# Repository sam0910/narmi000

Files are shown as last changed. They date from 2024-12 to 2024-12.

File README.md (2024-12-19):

## :rocket: 개발환경 구축

-   Clone this repository again, please refer pymakr.conf file.

-   Install Pymakr vscode extension - version 1.1.18

-   Modify pymakr.conf

```
"address": "COM6",
```

-   Click `X Pymakr Console`, now you can see REPL print-outs,

-   Then CTRL + C for interrupting device running processes.

-   Modify any of source file,

-   then click `All Commands - Pymakr > Upload Project`(bottom of VSC Code status line ).

-   Reset Device, boot.py and main.py will automatically running.

## :rocket: 테스트용 PWA 앱

-   React v18, Node v18.18.2 환경 입니다.

-   Shadcn UI 적용된 vite.js 패키지 입니다.

```
narmi000/REACT> npm install
narmi000/REACT> npm run dev
```

## :rocket: 펌웨어 업데이트

-   src/app 아래 파일들만 기기로 업데이트 됩니다.

-   기기전원 ON 후 즉시, 버튼 2개 누르고 있으면, 현재 깃헙 레포지토리 버젼(새로운 버젼 발견시)으로 펌웨어 업데이트 진행합니다.

-   WiFi 연결 시도 20~30초 소요되니 잠시 기다려 주세요.

    업데이트 모드 진입시,

    1. 주변 Wifi 중 와이파이 비번이 [src/app/common.py](https://github.com/sam0910/narmi000/blob/main/src/app/common.py) - INITIAL_WIFI_PASSWORD(12345678)인 AP로 연결 시도.
    2. [src/app/secrets.py](https://github.com/sam0910/narmi000/blob/main/src/app/secrets.py) 내의 지정된 Wifi로 접속 시도.

    ```
    WIFI_SSID = "KT_GiGA_xxxxx"
    WIFI_PASSWORD = "4bbbxxxxx"
    ```

    3. Wifi 연결 후 Github repo release version 체크 후 높은 버젼 발견시 src/app 아래 파일을 기기로 업데이트

## :rocket: 파일 설명

-   [src/boot.py](https://github.com/sam0910/narmi000/blob/main/src/boot.py) : 기기 On 시 제일 먼저 실행되는 파일입니다. 업데이트 모드 여부 판정 후 src/app/start.py 파일을 실행 합니다.

-   [src/app/start.py](https://github.com/sam0910/narmi000/blob/main/src/app/start.py) : 초기 실행 파일 입니다.

-   [src/calibration.py](https://github.com/sam0910/narmi000/blob/main/src/calibration.py) : 온습도 센서 보정치 저장파일 입니다.

-   [src/app/configuration.py](https://github.com/sam0910/narmi000/blob/main/src/app/configuration.py) : 설정파일입니다.

```
ENABLE_SLEEP = False  # Enable sleep mode
ADVERTIZING_LIMIT_MS = const(10_000)  # Advertising time in ms
SLEEP_TIME_S = const(5)  # Sleep Time in seconds
NO_INTERACTION = const(12_000)  # Time in ms to go to sleep if no interaction
INDICATE_TIMES = const(2)  # Number of times to indicate the sensor value per connection
```

    ### 펌웨어 관련은 [Micropython 관련문서](https://docs.micropython.org/en/latest/) 참고 부탁드립니다.

## :rocket: Bluetooth Characteristic

-   Temperature : 0x2A6E (signed 16-bit, little endian)

-   Humidity : 0x2A6F (unsigned 16-bit, little endian)

-   Distance : 0x2A5B (unsigned 16-bit, little endian)

-   Interval : 0x2A24 (unsigned 32-bit, little endian)

-   Battery Level : 0x2A19 (unsigned 8-bit)

-   Save Calibration data : 0x2B00 (unsigned 16-bit)

```
byte[] value = new byte[]{0x01, 0x02, 0x03, 0x04}; // Example byte array

// Unpack temp_calib as unsigned 16-bit
int tempCalibRaw = ByteBuffer.wrap(value, 0, 2).order(ByteOrder.LITTLE_ENDIAN).getShort() & 0xFFFF;
double tempCalib = tempCalibRaw / 100.0;

// Unpack humidity_calib as unsigned 16-bit
int humidityCalibRaw = ByteBuffer.wrap(value, 2, 2).order(ByteOrder.LITTLE_ENDIAN).getShort() & 0xFFFF;
double humidityCalib = humidityCalibRaw / 100.0;

// Print the results
System.out.println("Temperature Calibration: " + tempCalib);
System.out.println("Humidity Calibration: " + humidityCalib);
```

## :rocket: Micropython 파일 전송, [관련문서 링크](https://docs.micropython.org/en/latest/reference/mpremote.html)

```
$ pip install --user mpremote
mpremote connect COM4
```

윈도우 현재 폴더내의 test.txt 파일을 기기의 /app 폴더로 복사

```
mpremote cp test.txt :/app
```

## :rocket: USB UART

> CP2102 모듈 추천 ... [구매링크](https://robotscience.kr/goods/view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)
>
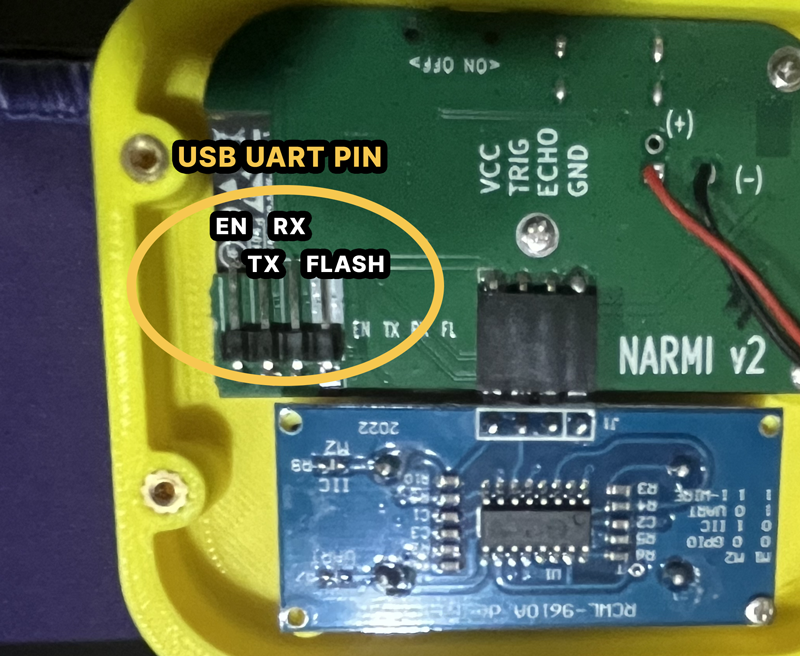
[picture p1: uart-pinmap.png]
Pinmap
> 

```

```

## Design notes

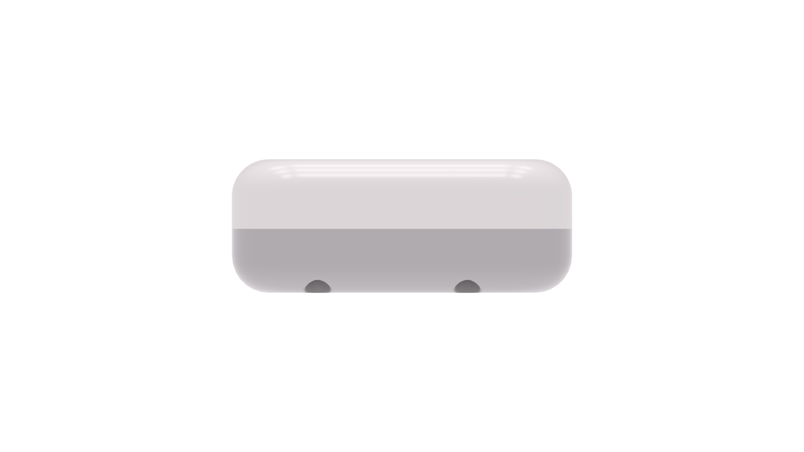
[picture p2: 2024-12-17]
CASE-3D/render/Ultrasonic-4.png

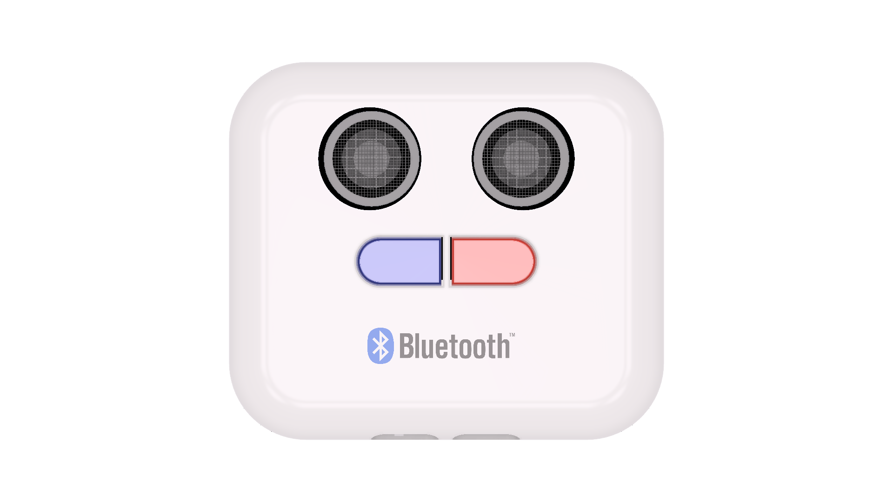
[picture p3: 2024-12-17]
CASE-3D/render/Ultrasonic-2.png

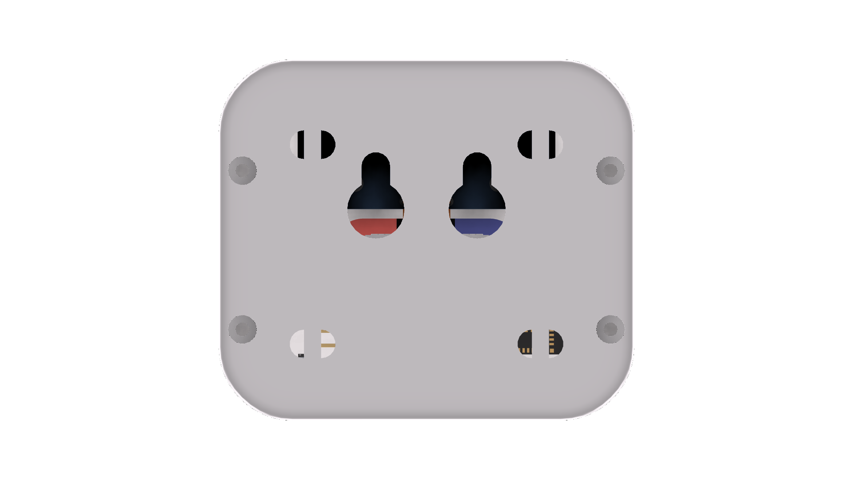
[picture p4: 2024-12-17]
CASE-3D/render/Ultrasonic-5.png

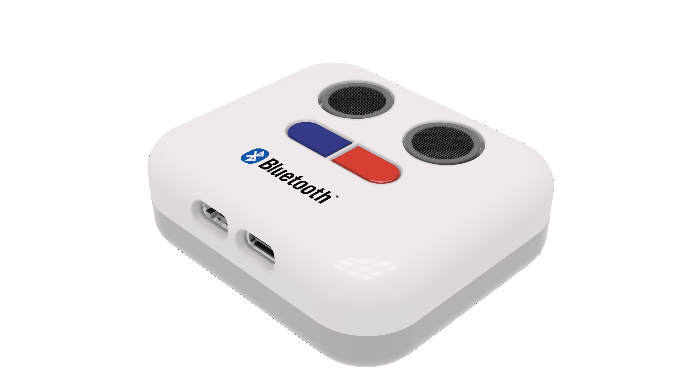
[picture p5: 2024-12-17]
CASE-3D/render/Ultrasonic v9.png

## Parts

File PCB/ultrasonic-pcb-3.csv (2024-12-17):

null | Sourced | Placed | References | Value | Footprint | Description | Datasheet | Quantity
1 |  | ✓ | C1, C2, C4, C13 | 100nF | C_0402_1005Metric |  |  | 4
2 |  | ✓ | C5, C6, C9, C10 | 4.7uF | C_0603_1608Metric | , Unpolarized capacitor |  | 4
3 |  | ✓ | C14 | 10uF | C_0603_1608Metric |  |  | 1
4 |  | ✓ | C17 | 1uF | C_0402_1005Metric |  |  | 1
5 |  | ✓ | R6, R7, R11, R15, R16, R20 | 100K | R_0402_1005Metric |  |  | 6
6 |  | ✓ | R4, R17, R18, R19 | 10K | R_0402_1005Metric |  |  | 4
7 |  | ✓ | R1, R2, R3 | 100R | C_0402_1005Metric | Resistor |  | 3
8 |  | ✓ | R8, R9 | 5K1 | R_0603_1608Metric | Resistor |  | 2
9 |  | ✓ | R5 | 1.5M | R_0402_1005Metric |  |  | 1
10 |  | ✓ | R10 | 500R | C_0402_1005Metric | Resistor |  | 1
11 |  | ✓ | R12 | 1K | R_0402_1005Metric |  |  | 1
12 |  | ✓ | R13 | 3K3 | R_0402_1005Metric |  |  | 1
13 |  |  | R14 | 470K | R_0402_1005Metric |  |  | 1
14 |  | ✓ | D2, D3, D5, D6 | LED | LED_0603_1608Metric | Light emitting diode | LY Q396-P1Q2-36 | 4
15 |  | ✓ | D1 | DESD5V0U1BL-7B | DESD5V0U1BL7B | ESD Suppressors / TVS Diodes LowCap BiDirectional 1Ch TVS 3A 250mW | https://www.diodes.com/assets/Datasheets/DESD5V0U1BL.pdf | 1
16 |  | ✓ | D4 | SD103AWS | SD103AWS | Schottky Barrier Diodes (SBD) SOD-323 RoHS | https://datasheet.lcsc.com/lcsc/1912111437_Shandong-Jingdao-Microelectronics-SD103AWS_C438010.pdf | 1
17 |  |  | U1 | ESP32-PICO-MINI-02U-N8R2 | MODULE_ESP32-PICO-MINI-02 |  |  | 1
18 |  |  | U2 | MAX17048G_T10 | MAX17048G_T10 |  |  | 1
19 |  | ✓ | U3 | SHT4x | Sensirion_DFN-4_1.5x1.5mm_P0.8mm_SHT4x_NoCentralPad | Digital Humidity and Temperature Sensor, +/-1%RH, +/-0.1degC, I2C, 1.08-3.6V, 16bit, DFN-4 | https://sensirion.com/media/documents/33FD6951/624C4357/Datasheet_SHT4x.pdf | 1
20 |  | ✓ | SW1, SW2 | TL6150 | TL6150 | MEC 5E single pole normally-open tactile switch | TL6150AF160QG | 2
21 |  | ✓ | H1, H3, H4 | MountingHole | MountingHole_2.2mm_M2_DIN965_Pad |  |  | 3
22 |  |  | FID1, FID2 | Fiducial | Fiducial_1.5mm_Mask3mm |  |  | 2
23 |  |  | FID3 | Fiducial | Fiducial_1mm_Mask2mm |  |  | 1
24 |  | ✓ | IC3 | RT9080-33GJ5 | SOT94P280X100-5N | IC REG LIN 3.3V 600MA TSOT23-5 | https://www.richtek.com/assets/product_file/RT9080/DS9080-05.pdf | 1
25 |  |  | IC5 | MCP73831-2DCI_MC | SON50P300X200X100-9N-D | Linear Battery Charger Controller Li-Ion/Li-Pol 505mA 4.2V 8-Pin DFN EP Tube | https://www.arrow.com/en/products/mcp73831-2dcimc/microchip-technology | 1
26 |  |  | Q1 | SIA517DJ-T1-GE3 | SIA537EDJT1GE3 |  | http://www.vishay.com/docs/64832/sia517dj.pdf | 1
27 |  |  | Q2 | NTA4151PT1G | NTA4151PT1G | ON Semiconductor NTA4151PT1G P-channel MOSFET Transistor, 0.76 A, -20 V, 3-Pin SC-75 | http://www.onsemi.com/pub/Collateral/NTA4151P-D.PDF | 1
28 |  |  | S1 | JS102011SAQN | SW_JS102011SAQN | Sub-Miniature Slide Switch-DPDT-0.3A@6VDC-Surface Mount-5,000 Cycles |  | 1
29 |  |  | TP6 | TestPoint | SolderWire-0.1sqmm_1x01_D0.4mm_OD1mm |  |  | 1
30 |  |  | J3 | Conn_01x02_Pin | PinHeader_1x02_P2.54mm_Horizontal | Generic connector, single row, 01x02, script generated |  | 1
31 |  |  | J4 | UJC-HP-3-SMT-TR | CUI_UJC-HP-3-SMT-TR |  |  | 1

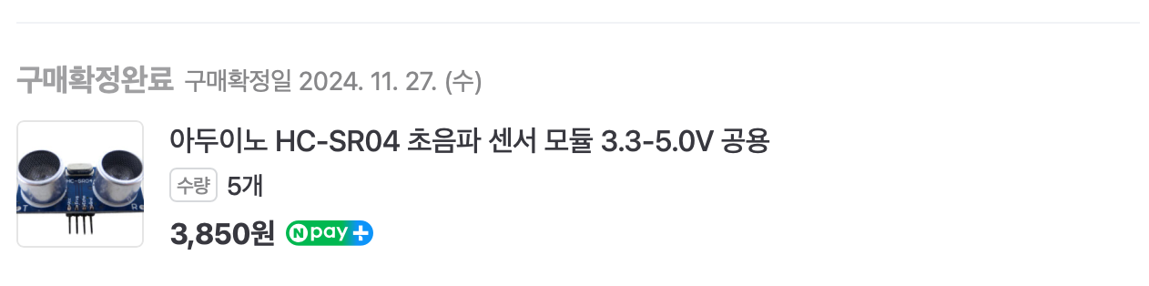
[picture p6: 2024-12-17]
PCB/material-estimates/증빙자료/초음파센서.png

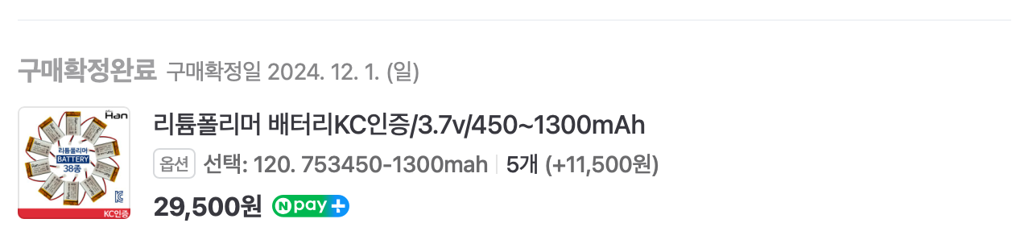
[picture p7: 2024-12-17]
PCB/material-estimates/증빙자료/배터리.png

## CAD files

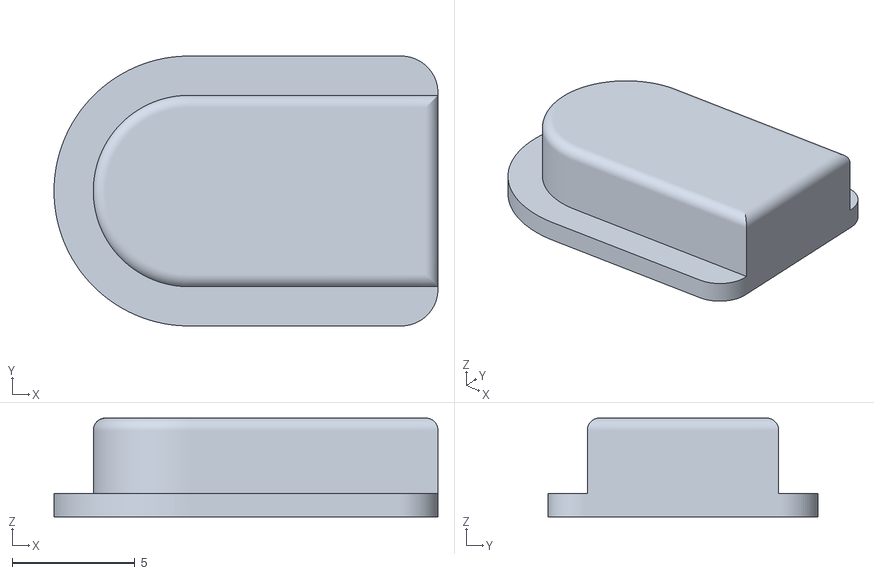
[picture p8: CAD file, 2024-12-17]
CASE-3D/STL/BUTTON.stl
15.6 x 11.0 x 4.03

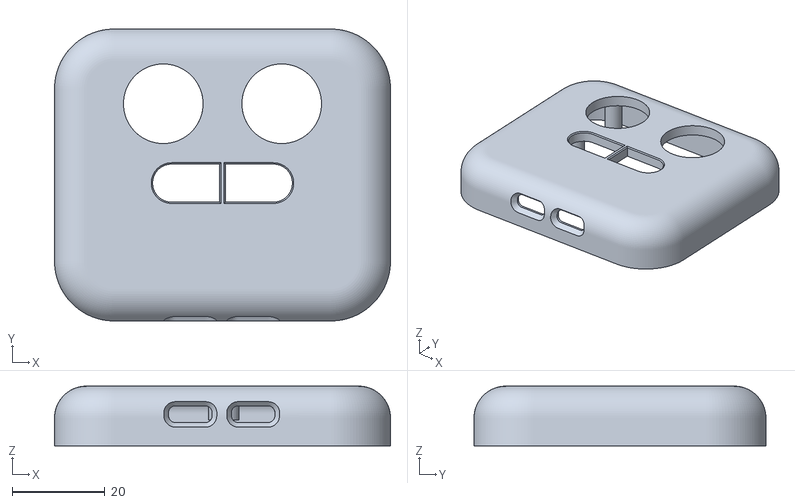
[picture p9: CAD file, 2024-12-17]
CASE-3D/STL/Top.stl
72.6 x 63.1 x 12.9

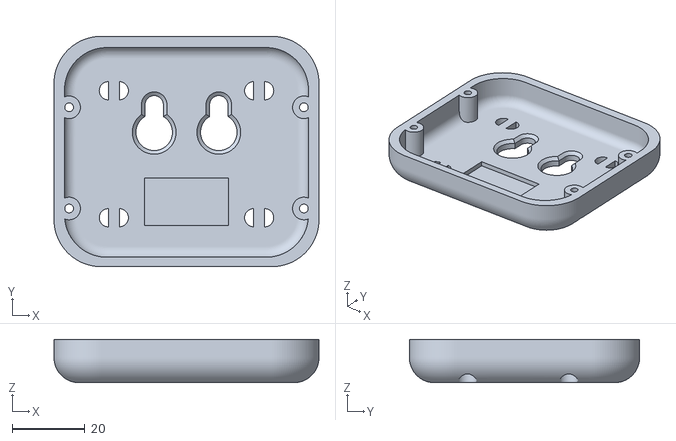
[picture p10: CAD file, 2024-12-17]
CASE-3D/STL/Bottom.stl
72.6 x 63.1 x 11.9

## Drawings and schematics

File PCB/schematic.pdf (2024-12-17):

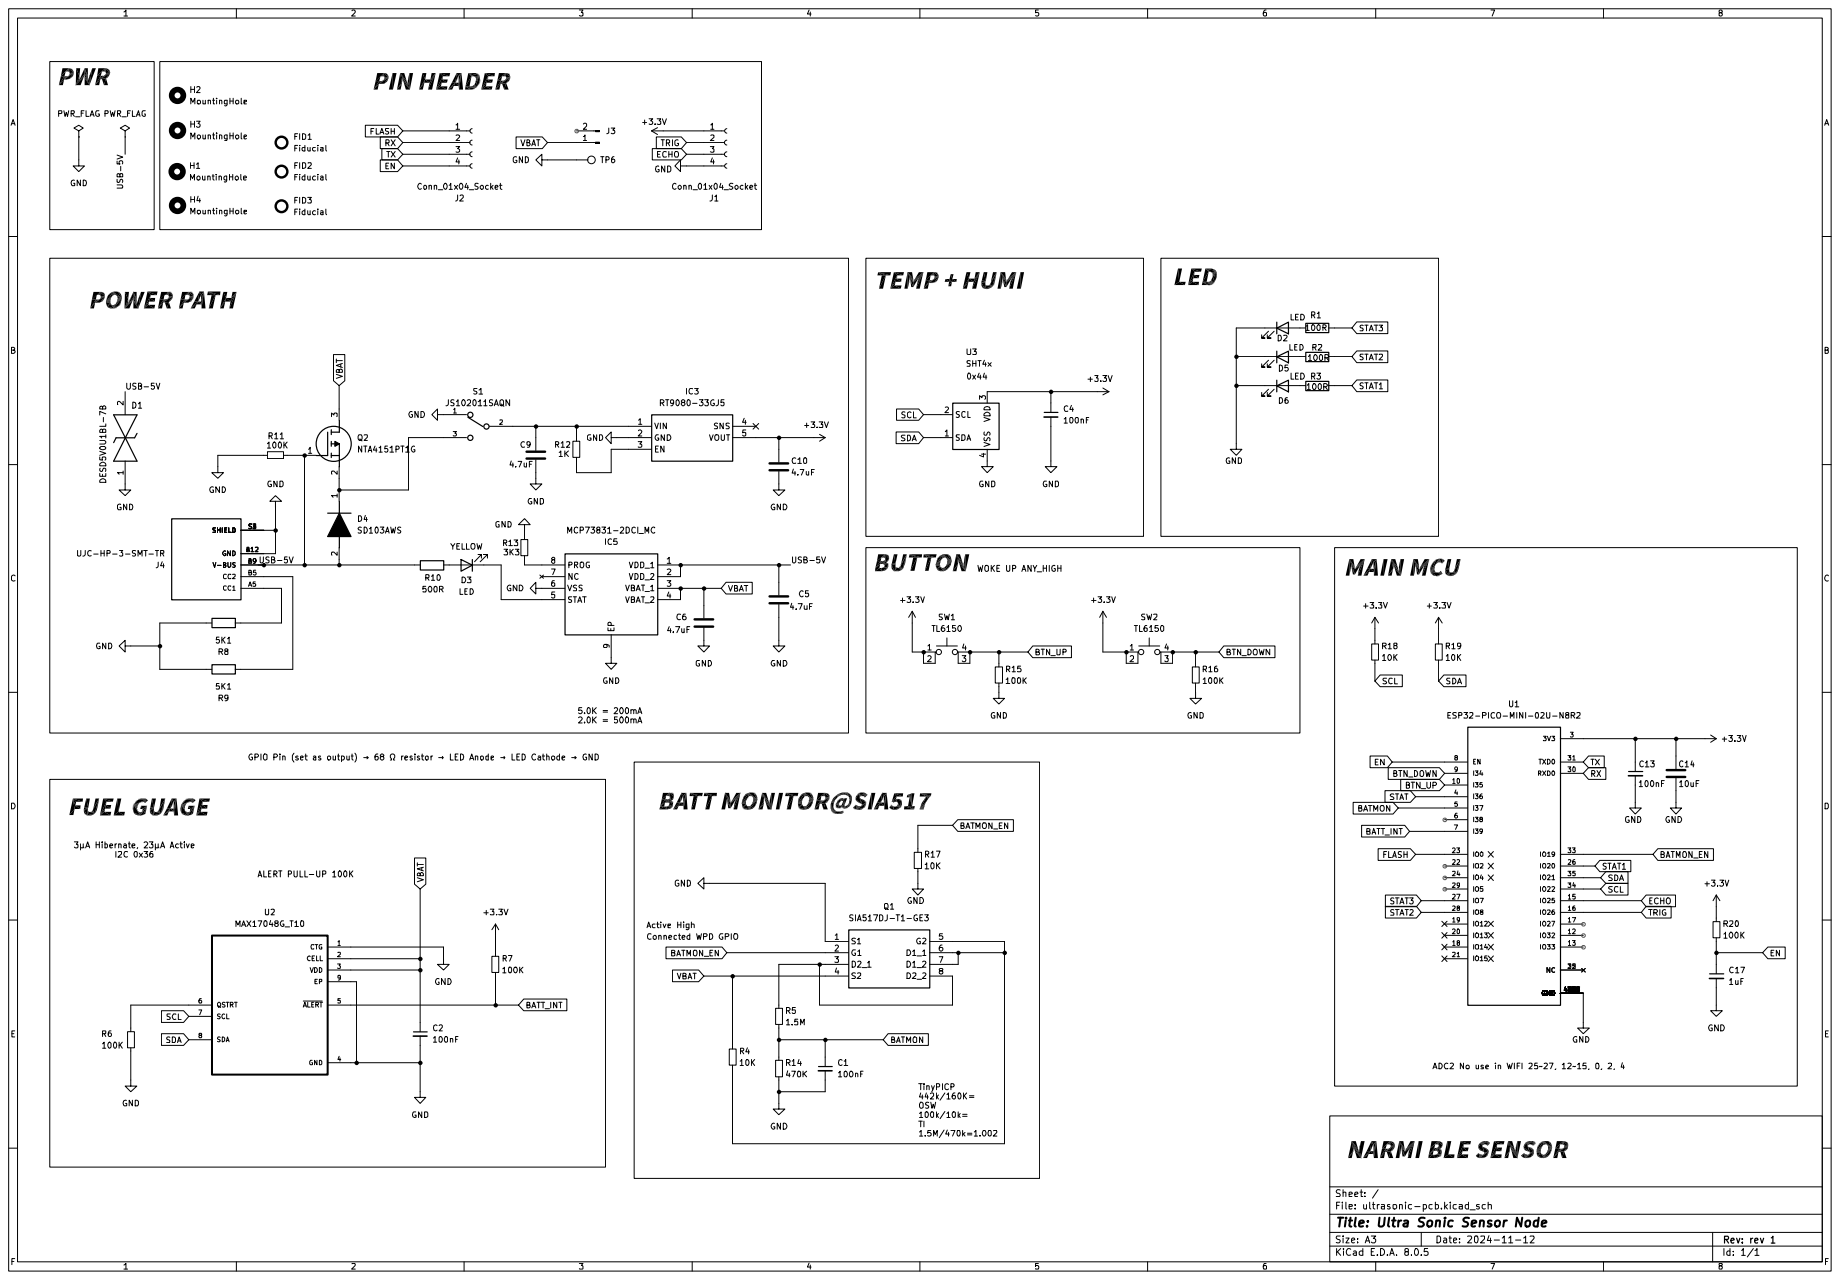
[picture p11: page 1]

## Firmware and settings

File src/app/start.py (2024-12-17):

print("Version 0.0.2 by local update")
import os

if "calibration.py" not in os.listdir():
    print("Creating default calibration.py")
    with open("calibration.py", "w") as f:
        f.write("CALIB_TEMP = 0.0\n")
        f.write("CALIB_HUMIDITY = 0.0\n")
import esp32
from machine import Pin, time_pulse_us, lightsleep, freq, SoftI2C, deepsleep
import uasyncio as asyncio
from micropython import const
import bluetooth
import random
import struct
import time
import json
import gc
import sys
import binascii
from app.aioble.ble_advertising import advertising_payload
from app.sensor.distance import HCSR04
from app.driver.iqsbuttons import IQSButtons
import app.common as common
from app.sensor.sht40.sht4xmod import SHT4xSensirion
from app.sensor.sht40.bus_service import I2cAdapter
from app.sensor.max17048 import max1704x
from calibration import CALIB_TEMP, CALIB_HUMIDITY
from app.configuration import *

gc.enable()
btn1 = Pin(34, Pin.IN, Pin.PULL_DOWN)
btn2 = Pin(35, Pin.IN, Pin.PULL_DOWN)
esp32.wake_on_ext1(pins=(btn1, btn2), level=esp32.WAKEUP_ANY_HIGH)


_IRQ_CENTRAL_CONNECT = const(1)
_IRQ_CENTRAL_DISCONNECT = const(2)
_IRQ_GATTS_WRITE = const(3)  # Add this line
_IRQ_GATTS_INDICATE_DONE = const(20)
_IRQ_ENCRYPTION_UPDATE = const(28)
_IRQ_PASSKEY_ACTION = const(31)
_IRQ_GET_SECRET = const(29)
_IRQ_SET_SECRET = const(30)
_FLAG_READ = const(0x0002)
_FLAG_NOTIFY = const(0x0010)
_FLAG_INDICATE = const(0x0020)
_FLAG_READ_ENCRYPTED = const(0x0200)
_FLAG_WRITE = const(0x0008)

# org.bluetooth.service.environmental_sensing
_ENV_SENSE_UUID = bluetooth.UUID(0x181A)
# org.bluetooth.characteristic.temperature
_TEMP_CHAR = (
    bluetooth.UUID(0x2A6E),
    _FLAG_READ | _FLAG_NOTIFY | _FLAG_INDICATE | _FLAG_READ_ENCRYPTED,
)
# Custom UUID for distance
_DISTANCE_CHAR_UUID = bluetooth.UUID(0x2A5B)
_DISTANCE_CHAR = (
    _DISTANCE_CHAR_UUID,
    _FLAG_READ | _FLAG_NOTIFY | _FLAG_INDICATE | _FLAG_READ_ENCRYPTED,
)
# Custom UUID for interval - using Time Interval characteristic
_INTERVAL_CHAR_UUID = bluetooth.UUID(0x2A24)
_INTERVAL_CHAR = (
    _INTERVAL_CHAR_UUID,
    _FLAG_READ | _FLAG_NOTIFY | _FLAG_INDICATE | _FLAG_READ_ENCRYPTED,
)
# org.bluetooth.characteristic.humidity
_HUMIDITY_CHAR_UUID = bluetooth.UUID(0x2A6F)
_HUMIDITY_CHAR = (
    _HUMIDITY_CHAR_UUID,
    _FLAG_READ | _FLAG_NOTIFY | _FLAG_INDICATE | _FLAG_READ_ENCRYPTED,
)
# Add new calibration characteristic UUID after existing UUIDs
_CALIB_CHAR_UUID = bluetooth.UUID(0x2B00)
_CALIB_CHAR = (
    _CALIB_CHAR_UUID,
    _FLAG_READ | _FLAG_WRITE | _FLAG_READ_ENCRYPTED,
)
# org.bluetooth.service.battery_service
_BATT_SVC_UUID = bluetooth.UUID(0x180F)
# org.bluetooth.characteristic.battery_level
_BATT_LVL_UUID = bluetooth.UUID(0x2A19)
_BATT_CHAR = (
    _BATT_LVL_UUID,
    _FLAG_READ | _FLAG_NOTIFY | _FLAG_INDICATE | _FLAG_READ_ENCRYPTED,
)
# org.bluetooth.characteristic.battery_voltage (custom UUID using 0x2B18)
_BATT_VOLT_UUID = bluetooth.UUID(0x2B18)
_BATT_VOLT_CHAR = (
    _BATT_VOLT_UUID,
    _FLAG_READ | _FLAG_NOTIFY | _FLAG_INDICATE | _FLAG_READ_ENCRYPTED,
)
_ENV_SENSE_SERVICE = (
    _ENV_SENSE_UUID,
    (
        _TEMP_CHAR,
        _DISTANCE_CHAR,
        _INTERVAL_CHAR,
        _HUMIDITY_CHAR,
        _CALIB_CHAR,  # Add calibration characteristic
    ),
)
_SERVICES = (
    _ENV_SENSE_SERVICE,
    (
        _BATT_SVC_UUID,
        (
            _BATT_CHAR,
            _BATT_VOLT_CHAR,
        ),
    ),
)
# org.bluetooth.characteristic.gap.appearance.xml
_ADV_APPEARANCE_GENERIC_THERMOMETER = const(768)
_IO_CAPABILITY_DISPLAY_ONLY = const(0)
_IO_CAPABILITY_DISPLAY_YESNO = const(1)
_IO_CAPABILITY_KEYBOARD_ONLY = const(2)
_IO_CAPABILITY_NO_INPUT_OUTPUT = const(3)
_IO_CAPABILITY_KEYBOARD_DISPLAY = const(4)
_PASSKEY_ACTION_INPUT = const(2)
_PASSKEY_ACTION_DISP = const(3)
_PASSKEY_ACTION_NUMCMP = const(4)
_ADDR_MODE = 0x00
# 0x00 - PUBLIC - Use the controller’s public address.
# 0x01 - RANDOM - Use a generated static address.
# 0x02 - RPA - Use resolvable private addresses.
# 0x03 - NRPA - Use non-resolvable private addresses.

freq(240_000_000)
gc.collect()
gc.enable()


def i2c_retry(retries=3, delay_ms=100):
    def decorator(func):
        def wrapper(*args, **kwargs):
            last_exception = None
            for attempt in range(retries):
                try:
                    return func(*args, **kwargs)
                except OSError as e:
                    last_exception = e
                    print(f"I2C operation failed, attempt {attempt + 1}/{retries}")
                    time.sleep_ms(delay_ms)
            print(f"I2C operation failed after {retries} attempts")
            return None

        return wrapper

    return decorator


class BLENarmi:
    def __init__(self, ble, name=DEVICE_NAME):
        self._ble = ble
        self.loop = asyncio.get_event_loop()
        # self.btns = IQSButtons(self.btn_cb, 35, 34, loop=self.loop)
        self._name = name
        self.t = 25
        self._load_secrets()
        self._ble.irq(self._irq)
        self._ble.config(bond=True)
        self._ble.config(le_secure=True)
        self._ble.config(mitm=True)
        self._ble.config(io=_IO_CAPABILITY_NO_INPUT_OUTPUT)
        self._ble.active(True)
        self._ble.config(addr_mode=_ADDR_MODE)
        self.distance = HCSR04()
        self.SLEEP_FOR_MS = SLEEP_TIME_S * 1000
        self.USER_INTERACTED = 0
        self.ADVERTIZING_TIME_MS = 0
        self.led = Pin(7, Pin.OUT, value=0)
        self.indicate_loop = None

        # Initialize SHT40 sensor
        self.i2c = SoftI2C(scl=Pin(22), sda=Pin(21), freq=100000)
        try:
            adaptor = I2cAdapter(self.i2c)
            self.sht = SHT4xSensirion(adaptor, address=0x44, check_crc=True)
            self.sht_available = True
        except Exception as e:
            print("SHT40 sensor init failed:", e)
            self.sht = None
            self.sht_available = False

        # Initialize battery sensor with better error handling
        self.battery = None
        try:
            self.battery = max1704x(self.i2c)
            # Test read to verify sensor is working
            soc, vcell = self.read_battery()
            if soc is None or vcell is None:
                raise ValueError("Battery sensor test read failed")
            print(f"Battery sensor initialized: SOC={soc}%, Voltage={vcell}V")
        except Exception as e:
            print("Battery sensor initialization failed:", e)
            self.battery = None

        # Update service registration to include calibration characteristic
        _ENV_SENSE_SERVICE = (
            _ENV_SENSE_UUID,
            (
                _TEMP_CHAR,
                _DISTANCE_CHAR,
                _INTERVAL_CHAR,
                _HUMIDITY_CHAR,
                _CALIB_CHAR,  # Add calibration characteristic
            ),
        )

        # Update service registration tuple unpacking
        (
            (
                self._temp_handle,
                self._distance_handle,
                self._interval_handle,
                self._humidity_handle,
                self._calib_handle,  # Add calibration handle
            ),
            (self._batt_level_handle, self._batt_volt_handle),
        ) = self._ble.gatts_register_services(_SERVICES)

        self._connections = set()
        self._payload = advertising_payload(
            name=name, services=[_ENV_SENSE_UUID], appearance=_ADV_APPEARANCE_GENERIC_THERMOMETER
        )
        self._pending_indications = {}  # Track pending indications
        print("BLE Device initialized and ready to advertise")
        self._advertise()

    def _irq(self, event, data):
        # Track connections so we can send notifications.
        if event == _IRQ_CENTRAL_CONNECT:
            conn_handle, _, _ = data
            print("\nConnected to central device")
            self._connections.add(conn_handle)
            self.indicate_loop = self.loop.create_task(self.start_indicating())

        elif event == _IRQ_CENTRAL_DISCONNECT:
            self.indicate_loop.cancel()
            conn_handle, _, _ = data
            print("\nDisconnected from central device")
            self._connections.remove(conn_handle)
            self._save_secrets()
            print("Starting advertising again...")
            self._advertise()
        elif event == _IRQ_ENCRYPTION_UPDATE:
            conn_handle, encrypted, authenticated, bonded, key_size = data
            print("encryption update", conn_handle, encrypted, authenticated, bonded, key_size)
        elif event == _IRQ_PASSKEY_ACTION:
            conn_handle, action, passkey = data
            print("passkey action", conn_handle, action, passkey)
            if action == _PASSKEY_ACTION_NUMCMP:
                accept = 1  # int(input("accept? "))
                self._ble.gap_passkey(conn_handle, action, accept)
            elif action == _PASSKEY_ACTION_DISP:
                print("displaying 1234")
                self._ble.gap_passkey(conn_handle, action, 1234)
            elif action == _PASSKEY_ACTION_INPUT:
                print("prompting for passkey")
                # passkey = int(input("passkey? "))
                self._ble.gap_passkey(conn_handle, action, passkey)
            else:
                print("unknown action")
        elif event == _IRQ_GATTS_INDICATE_DONE:
            conn_handle, value_handle, status = data
            if status == 0:
                print(f" -> Indication confirmed (handle: {conn_handle})")

            else:
                print(f"Indication failed (handle: {conn_handle}, status: {status})")
            if conn_handle in self._pending_indications:
                del self._pending_indications[conn_handle]
        elif event == _IRQ_SET_SECRET:
            sec_type, key, value = data
            key = sec_type, bytes(key)
            value = bytes(value) if value else None
            print("set secret:", key, value)
            if value is None:
                if key in self._secrets:
                    del self._secrets[key]
                    return True
                else:
                    return False
            else:
                self._secrets[key] = value
            return True
        elif event == _IRQ_GET_SECRET:
            sec_type, index, key = data
            print("get secret:", sec_type, index, bytes(key) if key else None)
            if key is None:
                i = 0
                for (t, _key), value in self._secrets.items():
                    if t == sec_type:
                        if i == index:
                            return value
                        i += 1
                return None
            else:
                key = sec_type, bytes(key)
                return self._secrets.get(key, None)
        # Add handler for write events
        elif event == _IRQ_GATTS_WRITE:
            conn_handle, attr_handle = data
            if attr_handle == self._calib_handle:
                # Read the written value
                value = self._ble.gatts_read(self._calib_handle)
                # Unpack calibration values
                temp_calib = struct.unpack("<h", value[0:2])[0] / 100
                humidity_calib = struct.unpack("<h", value[2:4])[0] / 100
                print(f"Received calibration values: temp={temp_calib}°C, humidity={humidity_calib}%")

                # Save to calibration file
                with open("calibration.py", "w") as f:
                    f.write(f"CALIB_TEMP = {temp_calib}\n")
                    f.write(f"CALIB_HUMIDITY = {humidity_calib}\n")

                # Optionally restart or update calibration immediately
                global CALIB_TEMP, CALIB_HUMIDITY
                CALIB_TEMP = temp_calib
                CALIB_HUMIDITY = humidity_calib

    def btn_cb(self, args):
        btn = args[0]
        type = args[1]
        print("     [BTN_CB],", btn, type)
        self.USER_INTERACTED = time.ticks_ms()
        if btn == 2 and type == 0:
            self.SLEEP_FOR_MS = self.SLEEP_FOR_MS + 1000
            self.set_interval(self.SLEEP_FOR_MS, indicate=True)
        elif btn == 1 and type == 0 and self.SLEEP_FOR_MS > 1000:
            self.SLEEP_FOR_MS = self.SLEEP_FOR_MS - 1000
            self.set_interval(self.SLEEP_FOR_MS, indicate=True)

    def set_temperature(self, temp_deg_c, notify=False, indicate=False):
        # Write the local value, ready for a central to read.
        self._ble.gatts_write(self._temp_handle, struct.pack("<h", int(temp_deg_c * 100)))
        if notify or indicate:
            for conn_handle in self._connections:
                if notify:
                    self._ble.gatts_notify(conn_handle, self._temp_handle)
                    print("- Sending TEMPERATURE notify")
                if indicate:
                    self._pending_indications[conn_handle] = time.ticks_ms()
                    self._ble.gatts_indicate(conn_handle, self._temp_handle)
                    print(f"- Sending TEMPERATURE indication (handle: {conn_handle})")

    def measure_distance(self):
        return self.distance.measure_distance_cm()

    def set_distance(self, distance_cm, notify=False, indicate=False):
        # Pack distance as uint16 in mm
        self._ble.gatts_write(self._distance_handle, struct.pack("<H", int(distance_cm * 10)))
        if notify or indicate:
            for conn_handle in self._connections:
                if notify:
                    self._ble.gatts_notify(conn_handle, self._distance_handle)
                if indicate:
                    self._pending_indications[conn_handle] = time.ticks_ms()
                    self._ble.gatts_indicate(conn_handle, self._distance_handle)
                    print(f"- Sending DISTANCE indication (handle: {conn_handle})")

    # Add new method to set interval
    def set_interval(self, interval_ms, notify=False, indicate=False):
        self._ble.gatts_write(self._interval_handle, struct.pack("<I", interval_ms))
        if notify or indicate:
            for conn_handle in self._connections:
                if notify:
                    self._ble.gatts_notify(conn_handle, self._interval_handle)
                if indicate:
                    self._pending_indications[conn_handle] = time.ticks_ms()
                    self._ble.gatts_indicate(conn_handle, self._interval_handle)
                    print(f"- Sending INTERVAL indication (handle: {conn_handle})")

    def set_humidity(self, humidity, notify=False, indicate=False):
        # Write humidity value (scaled by 100 to preserve 2 decimal places)
        self._ble.gatts_write(self._humidity_handle, struct.pack("<H", int(humidity * 100)))
        if notify or indicate:
            for conn_handle in self._connections:
                if notify:
                    self._ble.gatts_notify(conn_handle, self._humidity_handle)
                if indicate:
                    self._pending_indications[conn_handle] = time.ticks_ms()
                    self._ble.gatts_indicate(conn_handle, self._humidity_handle)
                    print(f"- Sending HUMIDITY indication (handle: {conn_handle})")

    def set_battery_level(self, level, notify=False, indicate=False):
        """Set battery level (0-100%)"""
        self._ble.gatts_write(self._batt_level_handle, struct.pack("<B", int(level)))
        if notify or indicate:
            for conn_handle in self._connections:
                if notify:
                    self._ble.gatts_notify(conn_handle, self._batt_level_handle)
                if indicate:
                    self._pending_indications[conn_handle] = time.ticks_ms()
                    self._ble.gatts_indicate(conn_handle, self._batt_level_handle)
                    print(f"- Sending BATTERY LEVEL indication (handle: {conn_handle})")

    def set_battery_voltage(self, voltage, notify=False, indicate=False):
        """Set battery voltage (in mV)"""
        self._ble.gatts_write(self._batt_volt_handle, struct.pack("<H", int(voltage * 1000)))
        if notify or indicate:
            for conn_handle in self._connections:
                if notify:
                    self._ble.gatts_notify(conn_handle, self._batt_volt_handle)
                if indicate:
                    self._pending_indications[conn_handle] = time.ticks_ms()
                    self._ble.gatts_indicate(conn_handle, self._batt_volt_handle)
                    print(f"- Sending BATTERY VOLTAGE indication (handle: {conn_handle})")

    def read_battery(self):
        """Read battery values from MAX17048 with better error handling"""
        if not self.battery:
            return None, None

        try:
            soc = self.battery.getSoc()
            vcell = self.battery.getVCell()
            # # Validate readings are within reasonable ranges
            # if not (0 <= soc <= 100 and 2.5 <= vcell <= 4.5):
            #     print("Battery readings out of valid range")
            #     return None, None
            # print("     Battery SOC: ", soc, "VCell: ", vcell)
            return soc, vcell
        except Exception as e:
            print("Battery read error:", e)

            print(sys.print_exception(e))
            self.battery = None  # Mark sensor as failed
            return None, None

    @i2c_retry(retries=3, delay_ms=100)
    def read_sht40(self):
        """Read temperature and humidity with retry logic"""
        if not self.sht_available:
            return None, None

        try:
            self.sht.start_measurement(with_heater=False, value=2)
            time.sleep_us(self.sht.get_conversion_cycle_time())
            results = self.sht.get_measurement_value()
            if results:
                temp, humidity = results
                # Validate readings are within reasonable ranges
                if -40 <= temp <= 125 and 0 <= humidity <= 100:
                    temp = temp + CALIB_TEMP
                    humidity = humidity + CALIB_HUMIDITY
                    return temp, humidity
                else:
                    print("Invalid sensor readings detected")
                    return None, None
            return None, None
        except Exception as e:
            print("SHT40 read error:", e)
            return None, None

    def _advertise(self, interval_us=200000):
        mac = self._ble.config("mac")
        mac_address_str = ":".join([f"{b:02x}" for b in mac[1]])
        print("\nStarting BLE advertising with address:", mac_address_str)
        self._payload = advertising_payload(
            name=self._name, services=[_ENV_SENSE_UUID], appearance=_ADV_APPEARANCE_GENERIC_THERMOMETER
        )
        self._ble.gap_advertise(interval_us, adv_data=self._payload)
        self.ADVERTIZING_TIME_MS = time.ticks_ms()

    def blink_led(self, times, delay):
        for _ in range(times):
            self.led.on()
            time.sleep_ms(delay)
            self.led.off()
            time.sleep_ms(delay)

    def _reset_secrets(self):
        self._secrets = []
        self._save_secrets()

    def _load_secrets(self):
        self._secrets = {}
        try:
            with open("secrets.json", "r") as f:
                entries = json.load(f)
                for sec_type, key, value in entries:
                    self._secrets[sec_type, binascii.a2b_base64(key)] = binascii.a2b_base64(value)
        except:
            print("no secrets available")

    def _save_secrets(self):
        try:
            with open("secrets.json", "w") as f:
                json_secrets = [
                    (sec_type, binascii.b2a_base64(key), binascii.b2a_base64(value))
                    for (sec_type, key), value in self._secrets.items()
                ]
                json.dump(json_secrets, f)
        except:
            print("failed to save secrets")

    async def check_buttons(self):
        while True:
            await asyncio.sleep_ms(500)
            print("Checking buttons", Pin(BTN_DOWN).value(), Pin(BTN_UP).value())

    def falling_asleep(self):
        print("Going to sleep")
        self.led.off()
        time.sleep_ms(100)
        if ENABLE_SLEEP:
            deepsleep(self.SLEEP_FOR_MS)

    async def go_sleep(self):
        while True:
            self.led.on()
            await asyncio.sleep_ms(200)
            self.led.off()
            await asyncio.sleep_ms(300)
            if self.USER_INTERACTED > 0:
                after_ineteracted = time.ticks_diff(time.ticks_ms(), self.USER_INTERACTED)
                if after_ineteracted >= NO_INTERACTION:
                    self.USER_INTERACTED = time.ticks_ms()
                    self.falling_asleep()
            if self.ADVERTIZING_TIME_MS > 0:
                after_advertizing = time.ticks_diff(time.ticks_ms(), self.ADVERTIZING_TIME_MS)
                if after_advertizing >= ADVERTIZING_LIMIT_MS:
                    self.ADVERTIZING_TIME_MS = time.ticks_ms()
                    self.falling_asleep()

    async def loops(self):
        # self.indicate_loop = self.loop.create_task(self.start_indicating())
        ps = self.loop.create_task(self.go_sleep())
        self.loop.run_forever()

    def start(self):

        self.btns = IQSButtons(self.btn_cb, BTN_DOWN, BTN_UP, loop=self.loop)
        # temp_task = self.loop.create_task(self.check_buttons())
        #

        try:
            asyncio.run(self.loops())

        except KeyboardInterrupt:
            print("Interrupted")
            # dist_task.cancel()
        finally:
            self.loop.close()
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

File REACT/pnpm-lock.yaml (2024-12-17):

lockfileVersion: '9.0'

settings:
  autoInstallPeers: true
  excludeLinksFromLockfile: false

importers:

  .:
    dependencies:
      '@radix-ui/react-label':
        specifier: ^2.1.0
        version: 2.1.1(@types/react-dom@18.3.5(@types/react@18.3.17))(@types/react@18.3.17)(react-dom@18.3.1(react@18.3.1))(react@18.3.1)
      '@radix-ui/react-slot':
        specifier: ^1.1.0
        version: 1.1.1(@types/react@18.3.17)(react@18.3.1)
      class-variance-authority:
        specifier: ^0.7.0
        version: 0.7.1
      clsx:
        specifier: ^2.1.1
        version: 2.1.1
      lucide-react:
        specifier: ^0.461.0
        version: 0.461.0(react@18.3.1)
      react:
        specifier: ^18.3.1
        version: 18.3.1
      react-dom:
        specifier: ^18.3.1
        version: 18.3.1(react@18.3.1)
      react-responsive:
        specifier: ^10.0.0
        version: 10.0.0(react@18.3.1)
      tailwind-merge:
        specifier: ^2.5.5
        version: 2.5.5
      tailwindcss-animate:
        specifier: ^1.0.7
        version: 1.0.7(tailwindcss@3.4.16)
    devDependencies:
      '@eslint/js':
        specifier: ^9.13.0
        version: 9.17.0
      '@types/node':
        specifier: ^22.9.4
        version: 22.10.2
      '@types/react':
        specifier: ^18.3.12
        version: 18.3.17
      '@types/react-dom':
        specifier: ^18.3.1
        version: 18.3.5(@types/react@18.3.17)
      '@vitejs/plugin-react':
        specifier: ^4.3.3
        version: 4.3.4(vite@5.4.11(@types/node@22.10.2))
      autoprefixer:
        specifier: ^10.4.20
        version: 10.4.20(postcss@8.4.49)
      eslint:
        specifier: ^9.13.0
        version: 9.17.0(jiti@1.21.6)
      eslint-plugin-react:
        specifier: ^7.37.2
        version: 7.37.2(eslint@9.17.0(jiti@1.21.6))
      eslint-plugin-react-hooks:
        specifier: ^5.0.0
        version: 5.1.0(eslint@9.17.0(jiti@1.21.6))
      eslint-plugin-react-refresh:
        specifier: ^0.4.14
        version: 0.4.16(eslint@9.17.0(jiti@1.21.6))
      globals:
        specifier: ^15.11.0
        version: 15.13.0
      postcss:
        specifier: ^8.4.49
        version: 8.4.49
      tailwindcss:
        specifier: ^3.4.15
        version: 3.4.16
      vite:
        specifier: ^5.4.10
        version: 5.4.11(@types/node@22.10.2)

packages:

  '@alloc/quick-lru@5.2.0':
    resolution: {integrity: sha512-UrcABB+4bUrFABwbluTIBErXwvbsU/V7TZWfmbgJfbkwiBuziS9gxdODUyuiecfdGQ85jglMW6juS3+z5TsKLw==}
    engines: {node: '>=10'}

  '@ampproject/remapping@2.3.0':
    resolution: {integrity: sha512-30iZtAPgz+LTIYoeivqYo853f02jBYSd5uGnGpkFV0M3xOt9aN73erkgYAmZU43x4VfqcnLxW9Kpg3R5LC4YYw==}
    engines: {node: '>=6.0.0'}

  '@babel/code-frame@7.26.2':
    resolution: {integrity: sha512-RJlIHRueQgwWitWgF8OdFYGZX328Ax5BCemNGlqHfplnRT9ESi8JkFlvaVYbS+UubVY6dpv87Fs2u5M29iNFVQ==}
    engines: {node: '>=6.9.0'}

  '@babel/compat-data@7.26.3':
    resolution: {integrity: sha512-nHIxvKPniQXpmQLb0vhY3VaFb3S0YrTAwpOWJZh1wn3oJPjJk9Asva204PsBdmAE8vpzfHudT8DB0scYvy9q0g==}
    engines: {node: '>=6.9.0'}

  '@babel/core@7.26.0':
    resolution: {integrity: sha512-i1SLeK+DzNnQ3LL/CswPCa/E5u4lh1k6IAEphON8F+cXt0t9euTshDru0q7/IqMa1PMPz5RnHuHscF8/ZJsStg==}
    engines: {node: '>=6.9.0'}

  '@babel/generator@7.26.3':
    resolution: {integrity: sha512-6FF/urZvD0sTeO7k6/B15pMLC4CHUv1426lzr3N01aHJTl046uCAh9LXW/fzeXXjPNCJ6iABW5XaWOsIZB93aQ==}
    engines: {node: '>=6.9.0'}

  '@babel/helper-compilation-targets@7.25.9':
    resolution: {integrity: sha512-j9Db8Suy6yV/VHa4qzrj9yZfZxhLWQdVnRlXxmKLYlhWUVB1sB2G5sxuWYXk/whHD9iW76PmNzxZ4UCnTQTVEQ==}
    engines: {node: '>=6.9.0'}

  '@babel/helper-module-imports@7.25.9':
    resolution: {integrity: sha512-tnUA4RsrmflIM6W6RFTLFSXITtl0wKjgpnLgXyowocVPrbYrLUXSBXDgTs8BlbmIzIdlBySRQjINYs2BAkiLtw==}
    engines: {node: '>=6.9.0'}

  '@babel/helper-module-transforms@7.26.0':
    resolution: {integrity: sha512-xO+xu6B5K2czEnQye6BHA7DolFFmS3LB7stHZFaOLb1pAwO1HWLS8fXA+eh0A2yIvltPVmx3eNNDBJA2SLHXFw==}
    engines: {node: '>=6.9.0'}
    peerDependencies:
      '@babel/core': ^7.0.0

  '@babel/helper-plugin-utils@7.25.9':
    resolution: {integrity: sha512-kSMlyUVdWe25rEsRGviIgOWnoT/nfABVWlqt9N19/dIPWViAOW2s9wznP5tURbs/IDuNk4gPy3YdYRgH3uxhBw==}
    engines: {node: '>=6.9.0'}

  '@babel/helper-string-parser@7.25.9':
    resolution: {integrity: sha512-4A/SCr/2KLd5jrtOMFzaKjVtAei3+2r/NChoBNoZ3EyP/+GlhoaEGoWOZUmFmoITP7zOJyHIMm+DYRd8o3PvHA==}
    engines: {node: '>=6.9.0'}

  '@babel/helper-validator-identifier@7.25.9':
    resolution: {integrity: sha512-Ed61U6XJc3CVRfkERJWDz4dJwKe7iLmmJsbOGu9wSloNSFttHV0I8g6UAgb7qnK5ly5bGLPd4oXZlxCdANBOWQ==}
    engines: {node: '>=6.9.0'}

  '@babel/helper-validator-option@7.25.9':
    resolution: {integrity: sha512-e/zv1co8pp55dNdEcCynfj9X7nyUKUXoUEwfXqaZt0omVOmDe9oOTdKStH4GmAw6zxMFs50ZayuMfHDKlO7Tfw==}
    engines: {node: '>=6.9.0'}
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

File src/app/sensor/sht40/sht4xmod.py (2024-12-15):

"""SHT4x Sensirion module"""

import time
from machine import I2C, Pin
from app.sensor.sht40 import bus_service
from app.sensor.sht40.base_sensor import BaseSensorEx, IBaseSensorEx, check_value
from app.sensor.sht40.crc_mod import crc8
from app.sensor.sht40.bus_service import I2cAdapter


def _calc_crc(sequence) -> int:
    """Wrapper for short call."""
    return crc8(sequence, polynomial=0x31, init_value=0xFF)


class SHT4xSensirion(BaseSensorEx, IBaseSensorEx):
    """Class for work with Sensirion SHT4x sensor"""

    cmd_get_id = 0x89
    cmd_soft_reset = 0x94
    magic = -1 + 2**16

    def __init__(self, adapter: bus_service.BusAdapter, address=0x44, check_crc: bool = True):
        """If check_crc is True, each data packet received from the sensor is verified
        for correctness by calculating the checksum."""
        check_value(address, range(0x44, 0x47), f"Invalid device address: {address}")
        super().__init__(adapter, address, True)
        self._check_crc = check_crc
        self._last_cmd_code = None
        #
        self._with_heater = None
        self._value = None
        self._long_pulse = None
        #
        self._buf_1 = bytearray(1)
        self._buf_6 = bytearray(6)

    # @staticmethod
    # def get_answer_len(command_code: int) -> int:
    #    """Возвращает количество байт в ответе датчика"""
    #    if SHT4xSensirion.cmd_soft_reset == command_code:
    #        return 0
    #    return 6

    def get_last_cmd_code(self) -> int:
        """Returns the last command code sent to the sensor via the bus"""
        return self._last_cmd_code

    def _send_command(self, command_code: int):
        """Sends command to sensor via bus"""
        check_value(command_code, range(0x100), f"Invalid command code: {command_code}")
        _local = self._buf_1
        _local[0] = command_code
        self.write(_local)
        self._last_cmd_code = command_code

    def _read_answer(self) -> [bytes, None]:
        """Reads response to command sent by _send_command method.
        Returns reference to buffer with received data.
        Checks CRC"""
        _cmd = self.get_last_cmd_code()
        if SHT4xSensirion.cmd_soft_reset == _cmd:
            return None
        _buf = self._buf_6
        self.read_to_buf(_buf)
        # response read
        if self._check_crc:
            crc_from_buf = [_buf[i] for i in (2, 5)]  # list with CRC values
            calculated_crc = [_calc_crc(_buf[rng.start : rng.stop]) for rng in (range(2), range(3, 5))]
            if crc_from_buf != calculated_crc:
                raise ValueError(f"Invalid CRC! Calculated: {calculated_crc}. From buffer: {crc_from_buf};")
        return _buf

    def get_id(self) -> tuple[int, int]:
        _cmd = SHT4xSensirion.cmd_get_id
        self._send_command(_cmd)
        # This 'wonder-sensor' cannot immediately return its programmed number! Need to call sleep_us!
        time.sleep_us(110)
        _buf = self._read_answer()
        t = self.unpack("HBH", _buf)
        # discard CRC
        return t[0], t[2]

    def soft_reset(self):
        """Software reset of the sensor. After reset, sensor enters idle state!"""
        self._send_command(SHT4xSensirion.cmd_soft_reset)

    def get_conversion_cycle_time(self) -> int:
        """Returns conversion time in microseconds(!) for signal to digital code conversion
        and its readiness for bus reading! For current sensor settings.
        When settings change, this method should be called again!"""
        if not self._with_heater:  # work without heating!
            _val = self._value  # 0..2; 0 - low, 1 - medium, 2 - high repeatability/accuracy
            _ms = 1_600, 4_500, 8_300
            return _ms[_val]

        if self._long_pulse:  # work with heating!
            return 1_100_000
        # short heating pulse
        return 110_000

    def start_measurement(self, with_heater: bool = False, value: int = 0, long_pulse: bool = False):
        """Configures sensor parameters and starts measurement process.
        with_heater - if True, measurement will be done with heating (NOT normal mode)
        value - repeatability if with_heater is False:
            0       - low (lowest accuracy)
            1       - medium (medium accuracy)
            2       - high (high accuracy)
        value - heater power if with_heater is True:
            0       -   20 mW
            1       -   110 mW
            2       -   200 mW
        long_pulse - heating duration, used if with_heater is True:
            False   -   0.1 sec
            True    -   1.0 sec"""
        check_value(value, range(3), f"Invalid value: {value}")

        _cmd = None
        if not with_heater:
            # heater NOT used! 0xE0, 0xF6, 0xFD
            _t = 0xE0, 0xF6, 0xFD
            _cmd = _t[value]

        if with_heater:
            # heater used! (0x15, 0x1E), (0x24, 0x2F), (0x32, 0x39)
            _t = (0x15, 0x1E), (0x24, 0x2F), (0x32, 0x39)
            _cmd = _t[value][long_pulse]

        self._send_command(_cmd)
        # get_conversion_cycle_time
        self._with_heater = with_heater
        self._value = value
        self._long_pulse = long_pulse

    def get_measurement_value(self) -> [None, tuple[float, float]]:
        _cmd = self.get_last_cmd_code()
        if SHT4xSensirion.cmd_get_id == _cmd:
            return
        _buf = self._read_answer()
        _t = self.unpack("HBH", _buf)
        t = 175.0 * _t[0] / SHT4xSensirion.magic - 45.0
        rh = 125.0 * _t[2] / SHT4xSensirion.magic - 6.0
        return t, rh

    def is_single_shot_mode(self) -> bool:
        return True
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

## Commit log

2024-12-15 [1215/20:09] calibration temp, humi
2024-12-17 [1217/10:15] characteristic, pcb gerber
    [BUTTON.stl, Bottom.stl, Top.stl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]
2024-12-17 [1217/11:28] implement save calibration data for temp, humi
2024-12-17 [1217/11:40] fix missing auto start
    [boot.py]
2024-12-17 [1217/14:41] Update download led blinking
2024-12-17 [1217/15:02] Update final bom estimates
